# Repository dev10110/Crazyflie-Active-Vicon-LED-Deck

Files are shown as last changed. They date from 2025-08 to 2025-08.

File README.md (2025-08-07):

# Crazyflie-Active-Vicon-LED-Deck

This repo contains the PCB layout for a vicon active marker deck for crazyflies. 

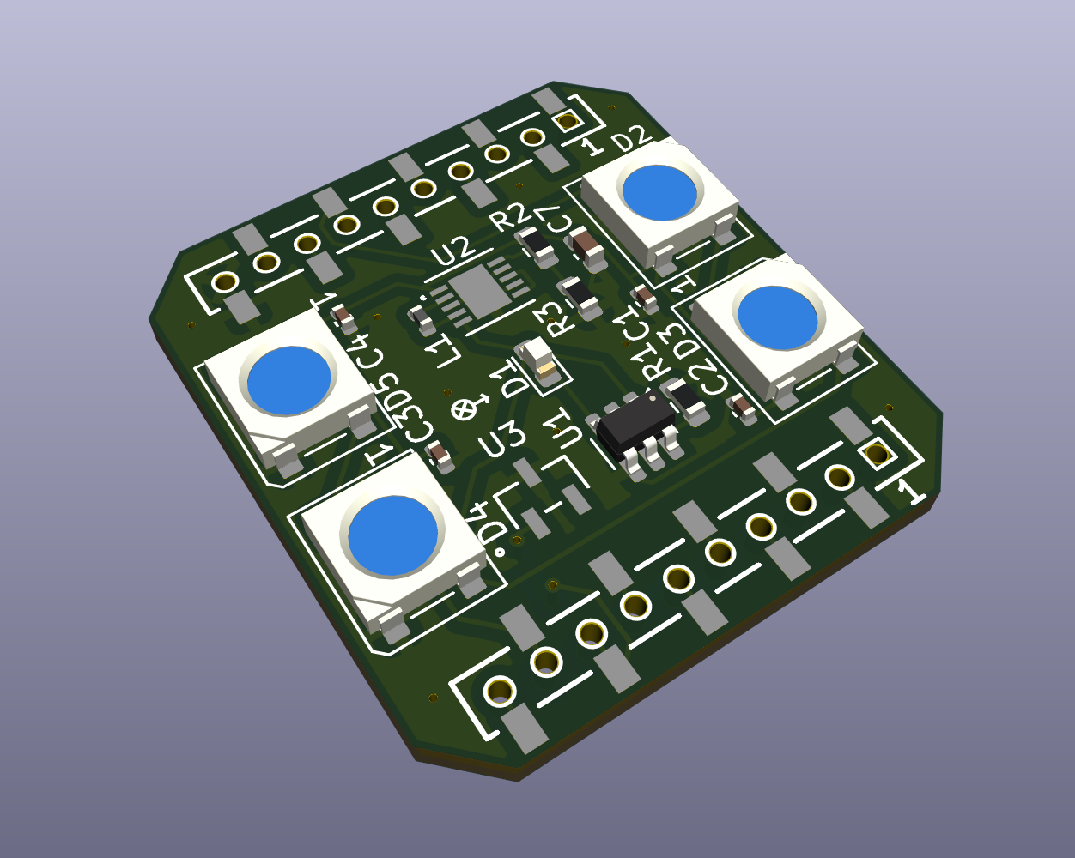
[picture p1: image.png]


The PCB was designed in Kicad9, following the reference schematics of the [BitCraze LED Deck](https://www.bitcraze.io/products/led-ring-deck/), and the [ETH-PBL Active Vicon Marker Deck](https://github.com/ETH-PBL/Active-motion-capture-marker-deck).

The main components on the board are 
- 850 nm LED [HIR19-21C/L11/TR8](https://www.digikey.com/en/products/detail/everlight-electronics-co-ltd/HIR19-21C-L11-TR8/2675838)
- 4x RGB LED [WS2812B](https://jlcpcb.com/api/file/downloadByFileSystemAccessId/8588893982302875648)
- Buck-Boost Converter (to mainain 3.8V) [STBB1-APUR](https://www.st.com/resource/en/datasheet/stbb1-axx.pdf)
- One-Wire Memory EEPROM [DS28E05R+T](https://www.analog.com/media/en/technical-documentation/data-sheets/DS28E05.pdf)

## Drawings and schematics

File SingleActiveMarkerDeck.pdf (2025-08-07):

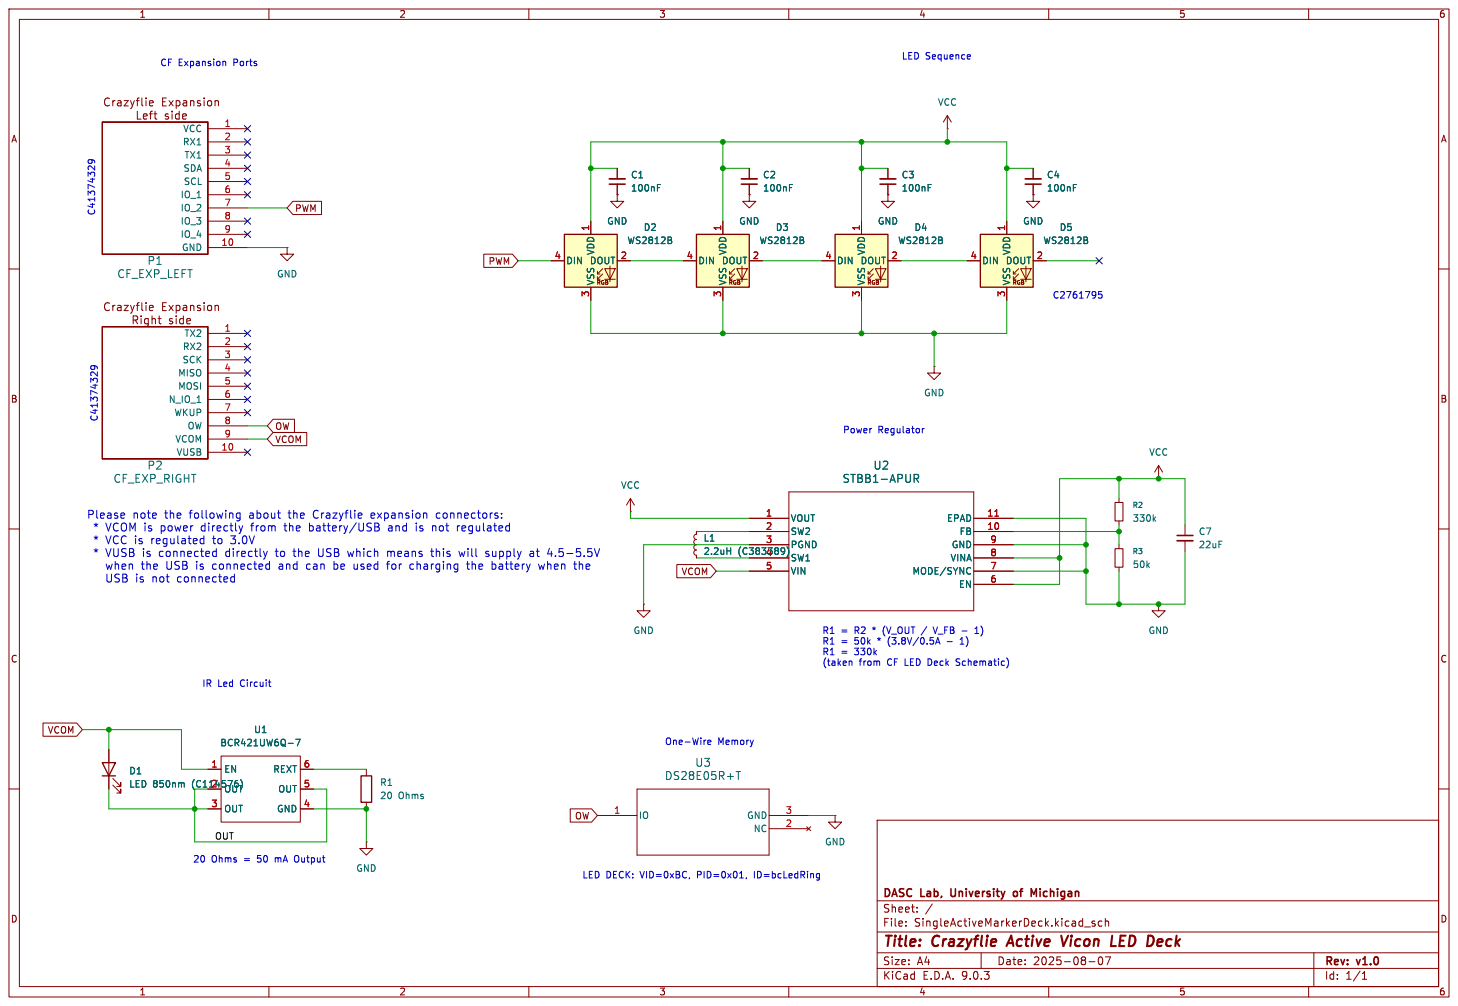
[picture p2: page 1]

IR Led Circuit 20 Ohms = 50 mA Output

Id: 1/1 Title: Crazyflie Active Vicon LED Deck

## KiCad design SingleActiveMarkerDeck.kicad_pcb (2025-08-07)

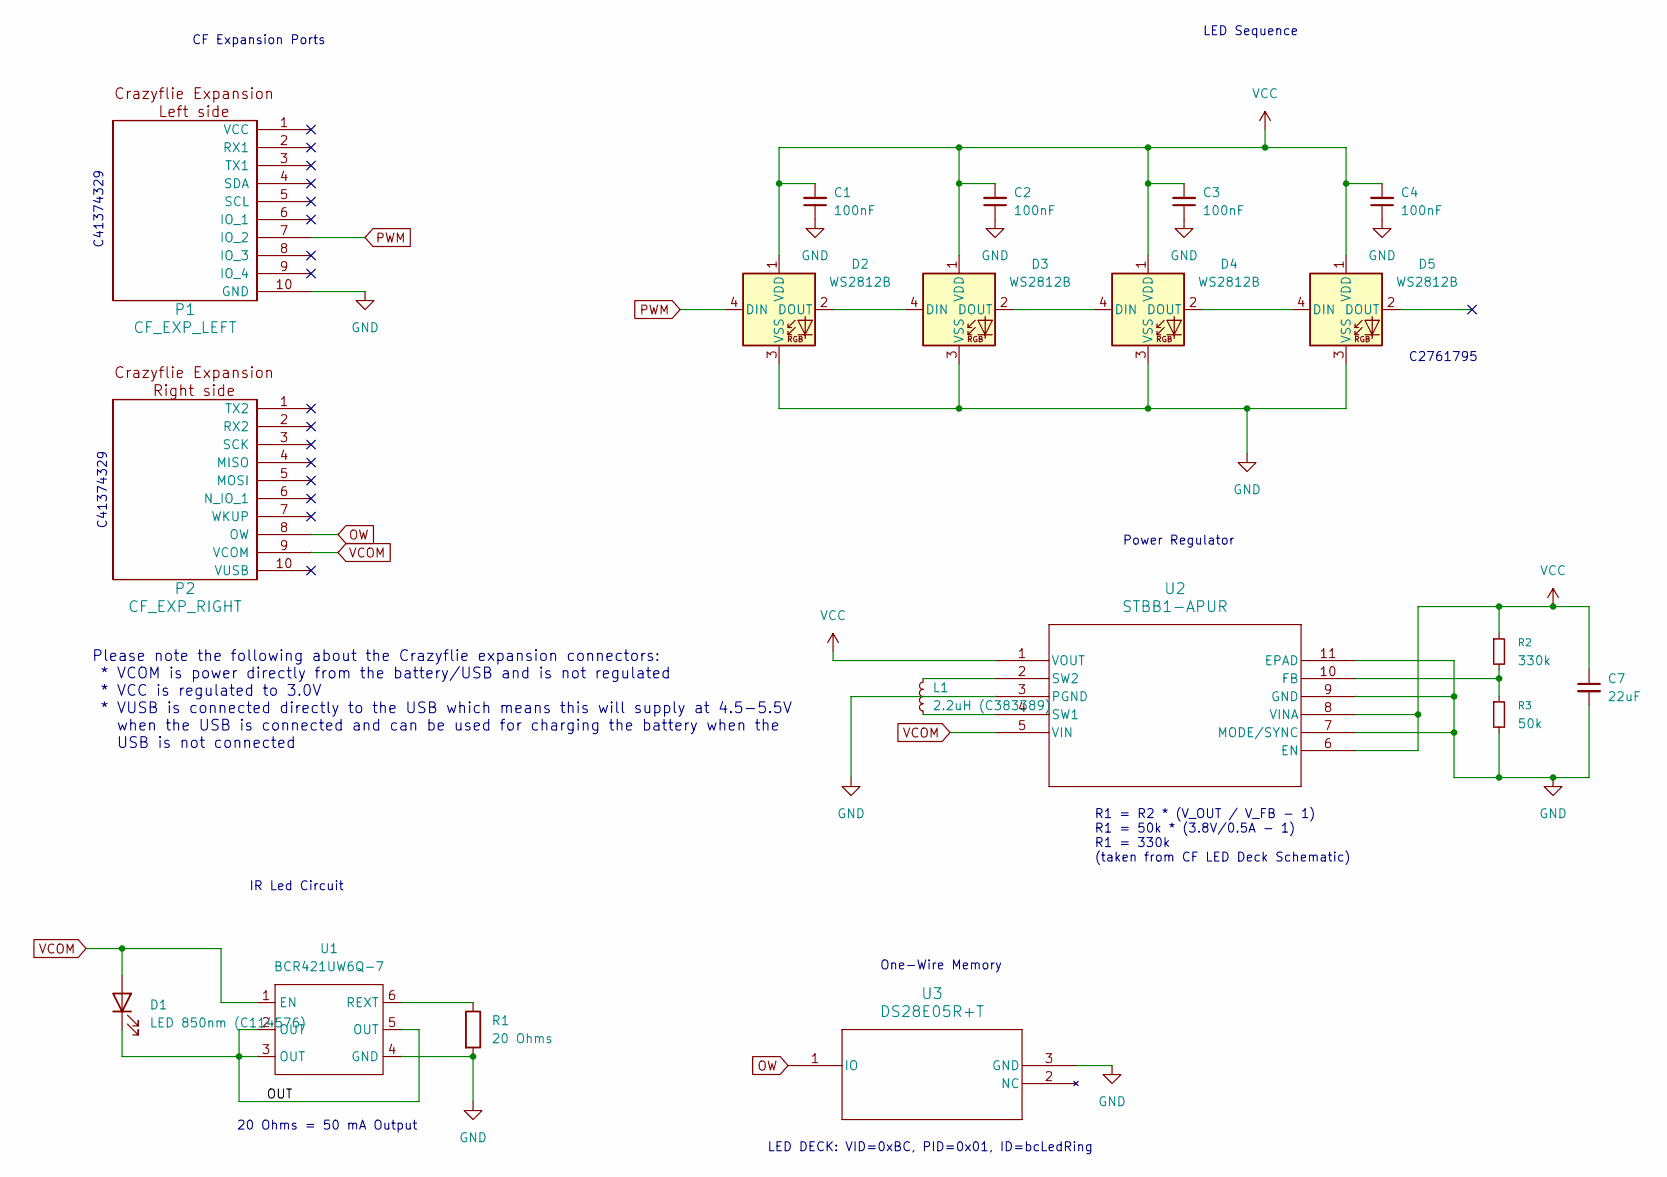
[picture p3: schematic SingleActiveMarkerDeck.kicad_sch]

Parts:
C1, C2, C3, C4: 100nF; C_0402_1005Metric
C7: 22uF; C_0603_1608Metric
D1: LED 850nm (C114576); LED_0603_1608Metric
D2, D3, D4, D5: WS2812B; LED_WS2812B_PLCC4_5.0x5.0mm_P3.2mm
L1: 2.2uH (C383389); L_0402_1005Metric
P1: CF_EXP_LEFT
P2: CF_EXP_RIGHT
R1: 20 Ohms; R_0603_1608Metric
R2: 330k; R_0603_1608Metric
R3: 50k; R_0603_1608Metric
U1: BCR421UW6Q-7; SOT-23-6
U2: STBB1-APUR; SON_B1-APUR_STM
U3: DS28E05R+T; 21-0051H_MXM

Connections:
/OUT: D1.1 (K), U1.2 (OUT), U1.3 (OUT), U1.5 (OUT)
GND: C1.1, C2.1, C3.1, C4.1, C7.2, D2.3 (VSS), D3.3 (VSS), D4.3 (VSS), D5.3 (VSS), P1.10 (GND), R1.2, R3.2, U1.4 (GND), U2.3 (PGND), U2.7 (MODE/SYNC), U2.9 (GND), U2.11 (EPAD), U3.3 (GND)
unnamed: D2.2 (DOUT), D3.4 (DIN)
unnamed: D3.2 (DOUT), D4.4 (DIN)
unnamed: D4.2 (DOUT), D5.4 (DIN)
unnamed: R1.1, U1.6 (REXT)
unnamed: R2.2, R3.1, U2.10 (FB)
unnamed: L1.1, U2.4 (SW1)
unnamed: L1.2, U2.2 (SW2)
OW: P2.8 (OW), U3.1 (IO)
PWM: D2.4 (DIN), P1.7 (IO_2)
VCC: C1.2, C2.2, C3.2, C4.2, C7.1, D2.1 (VDD), D3.1 (VDD), D4.1 (VDD), D5.1 (VDD), R2.1, U2.1 (VOUT), U2.6 (EN), U2.8 (VINA)
VCOM: D1.2 (A), P2.9 (VCOM), U1.1 (EN), U2.5 (VIN)

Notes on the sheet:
C2761795
LED Sequence
CF Expansion Ports
R1 = R2 * (V_OUT / V_FB - 1) R1 = 50k * (3.8V/0.5A - 1) R1 = 330k (taken from CF LED Deck Schematic)
C41374329
IR Led Circuit
One-Wire Memory
Power Regulator
20 Ohms = 50 mA Output
LED DECK: VID=0xBC, PID=0x01, ID=bcLedRing
Please note the following about the Crazyflie expansion connectors: * VCOM is power directly from the battery/USB and is not regulated * VCC is regulated to 3.0V * VUSB is connected directly to the USB which means this will supply at 4.5-5.5V when the USB is connected and can be used for charging t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

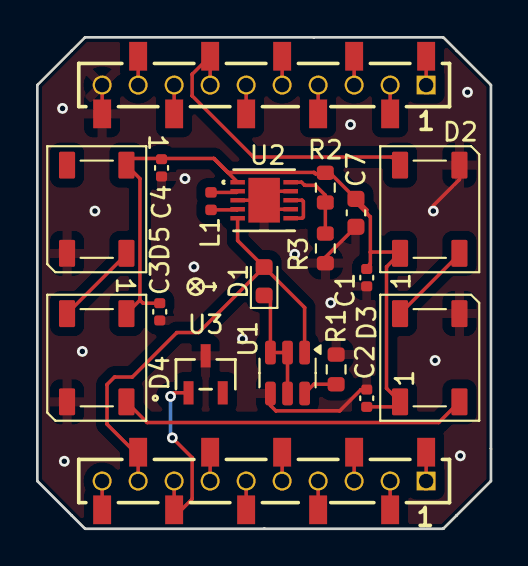
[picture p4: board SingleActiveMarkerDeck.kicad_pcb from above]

Board: 2 copper layers, 25.2 x 27.3 mm, 19 parts (0 on the bottom side), 13 nets.
